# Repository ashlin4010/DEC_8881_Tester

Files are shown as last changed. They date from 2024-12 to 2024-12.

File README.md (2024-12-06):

# DEC_8881_Tester
A simple tester for DEC 8881 chips.

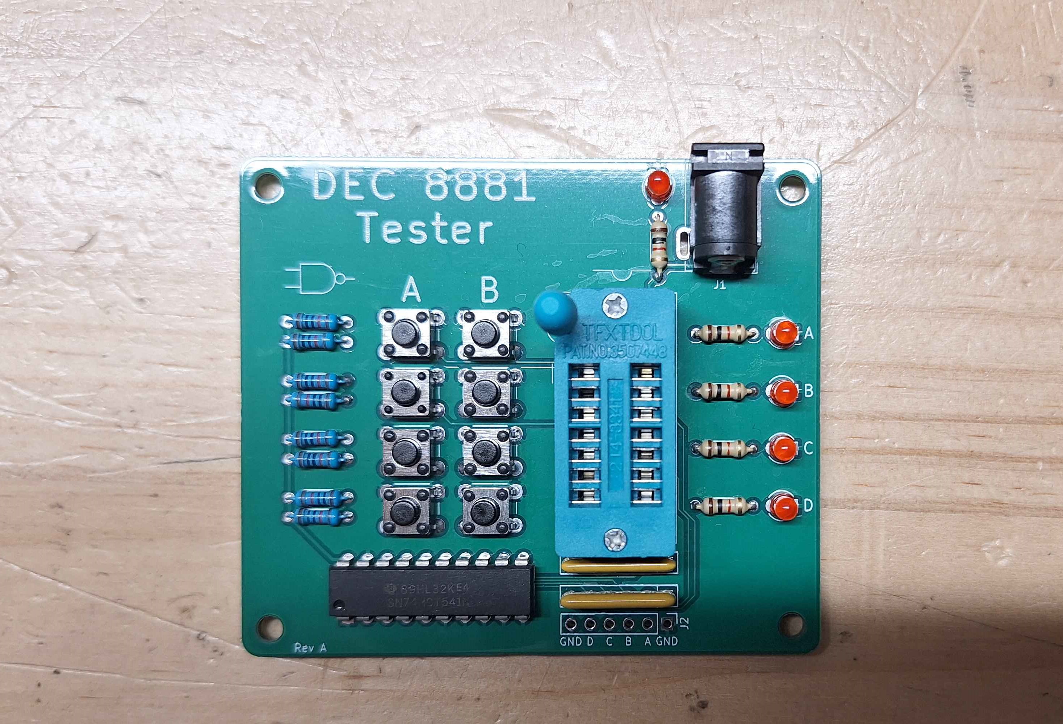
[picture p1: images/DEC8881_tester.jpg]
Chip Tester PCB


## Usage ##
 1. Plug it into 5 volt power centre positive power.
 2. Install chip
 3. Press Buttons

## Bill of materials ##

| Quantity | Part | Link |
|:---:|:---:|:---:|
| 5 | 1K Resistor |  |
| 8 | 10K Resistor |  |
| 8 | Push Button | https://www.digikey.co.nz/en/products/detail/same-sky-formerly-cui-devices/TS02-66-70-BK-160-LCR-D/15634243 |
| 1 | Barrel Jack | https://www.digikey.co.nz/en/products/detail/same-sky-formerly-cui-devices/PJ-037A/1644545 |
| 1 | DIP-14 ZIF Socket | https://www.aliexpress.com/item/1005007048855354.html |
| 1 | 74HCT541 | https://www.digikey.co.nz/en/products/detail/texas-instruments/SN74HCT541N/277265 |
| 1 | 390ohm Bussed | https://www.digikey.co.nz/en/products/detail/bourns-inc/4606X-101-391LF/1088986 |
| 1 | 180ohm Bussed | https://www.digikey.co.nz/en/products/detail/bourns-inc/4606X-101-181LF/1088969 |
| 5 | 3mm LED RED |  |

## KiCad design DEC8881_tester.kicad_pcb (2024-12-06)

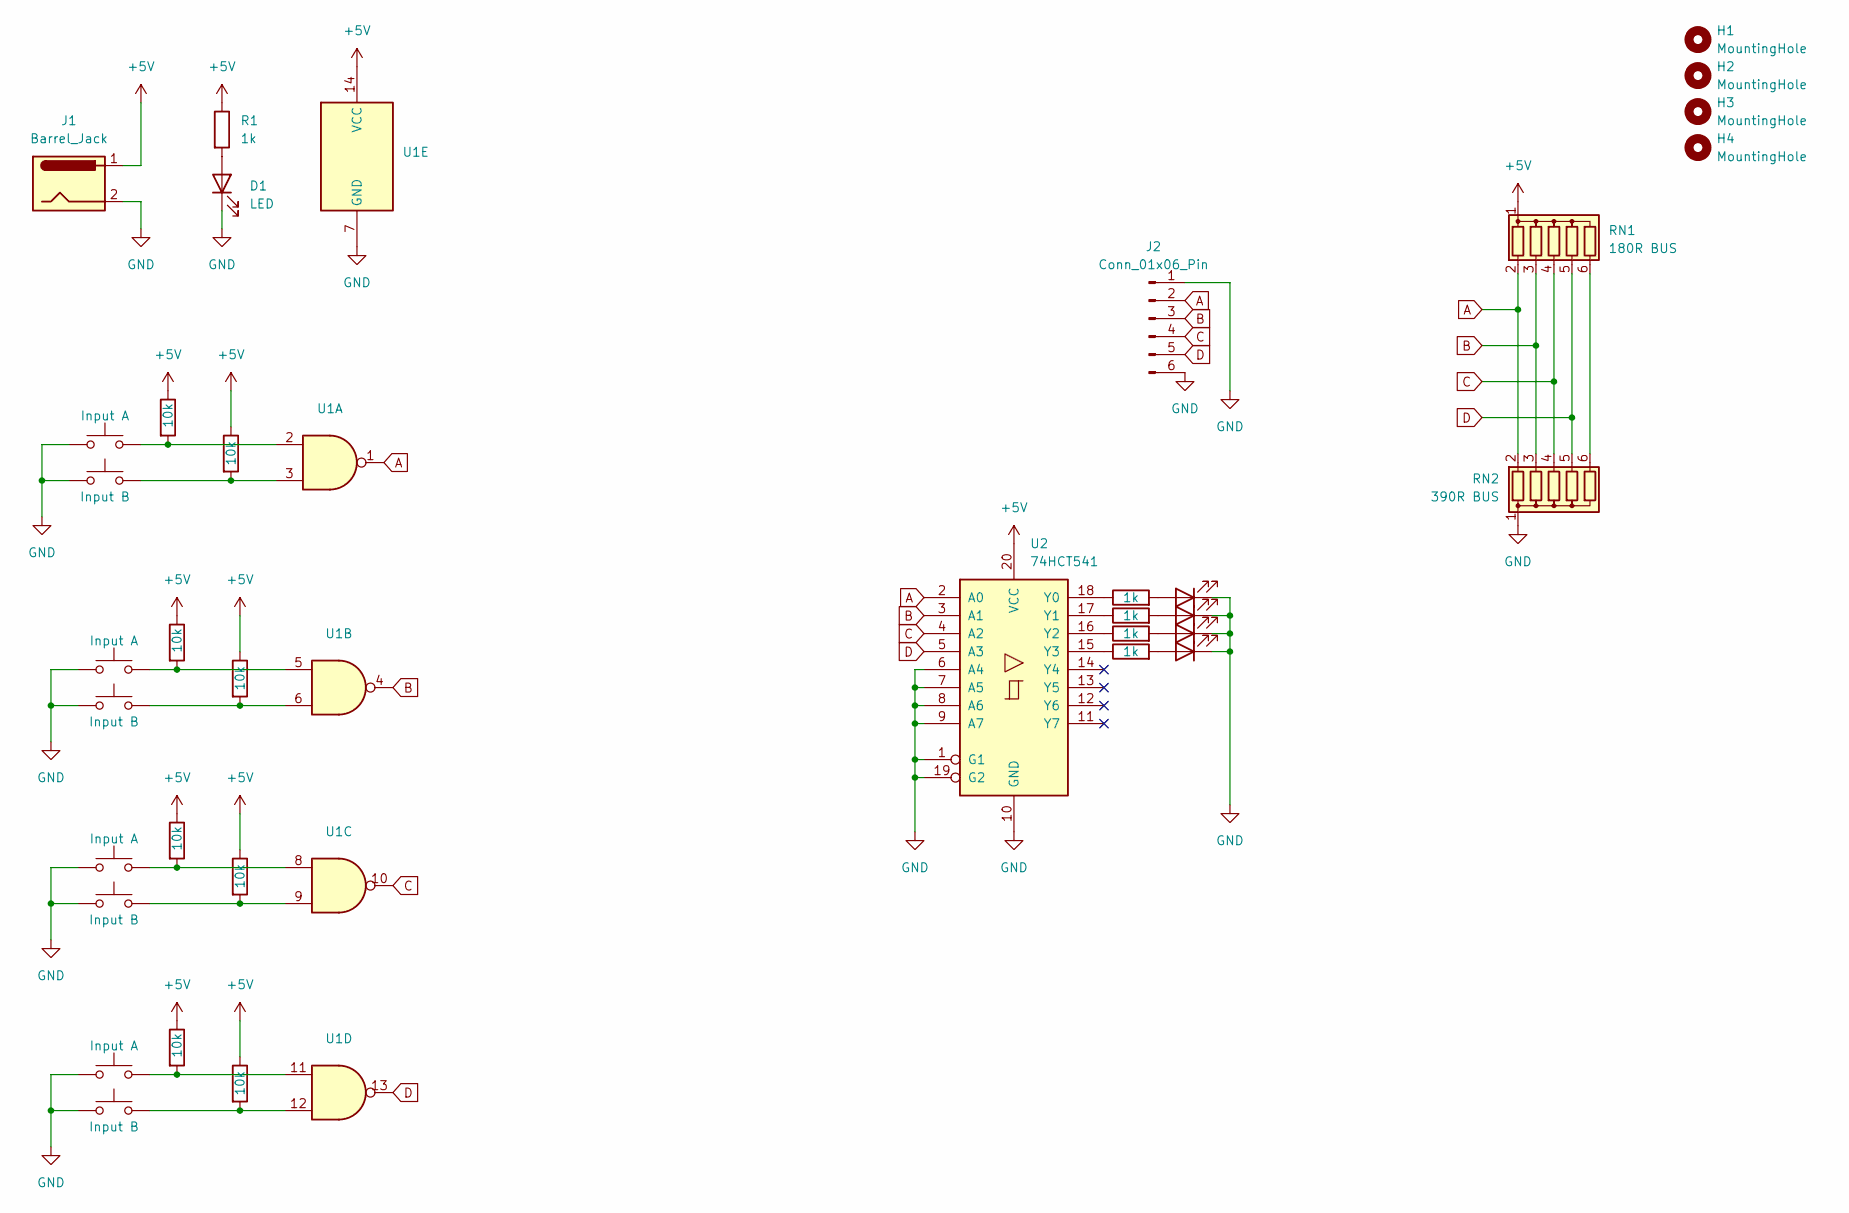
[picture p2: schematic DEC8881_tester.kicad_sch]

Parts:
D1, D2, D3, D4, D5: LED; LED_D3.0mm
H1, H2, H3, H4: MountingHole; MountingHole_3.2mm_M3
J1: Barrel_Jack; BarrelJack_GCT_DCJ200-10-A_Horizontal
J2: Conn_01x06_Pin; PinHeader_1x06_P2.54mm_Vertical
R1, R10, R11, R12, R13: 1k; R_Axial_DIN0204_L3.6mm_D1.6mm_P7.62mm_Horizontal
R2, R3, R4, R5, R6, R7, R8, R9: 10k; R_Axial_DIN0204_L3.6mm_D1.6mm_P7.62mm_Horizontal
RN1: 180R BUS; R_Array_SIP6
RN2: 390R BUS; R_Array_SIP6
SW1, SW3, SW5, SW7: Input A; SW_PUSH_6mm_H4.3mm
SW2, SW4, SW6, SW8: Input B; SW_PUSH_6mm_H4.3mm
U1: DIP_Socket-14_W4.3_W5.08_W7.62_W10.16_W10.9_3M_214-3339-00-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
U2: 74HCT541; DIP-20_W7.62mm

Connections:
+5V: J1.1, R1.1, R2.1, R3.1, R4.1, R5.1, R6.1, R7.1, R8.1, R9.1, RN1.1 (common), U1.14 (VCC), U2.20 (VCC)
A: J2.2, RN1.2 (R1), RN2.2 (R1), U1.1, U2.2 (A0)
B: J2.3, RN1.3 (R2), RN2.3 (R2), U1.4, U2.3 (A1)
C: J2.4, RN1.4 (R3), RN2.4 (R3), U1.10, U2.4 (A2)
D: J2.5, RN1.5 (R4), RN2.5 (R4), U1.13, U2.5 (A3)
GND: D1.1 (K), D2.1 (K), D3.1 (K), D4.1 (K), D5.1 (K), J1.2, J2.1, J2.6, RN2.1 (common), SW1.1, SW2.1, SW3.1, SW4.1, SW5.1, SW6.1, SW7.1, SW8.1, U1.7 (GND), U2.1 (G1), U2.6 (A4), U2.7 (A5), U2.8 (A6), U2.9 (A7), U2.10 (GND), U2.19 (G2)
unnamed: D1.2 (A), R1.2
unnamed: D2.2 (A), R10.2
unnamed: D3.2 (A), R11.2
unnamed: D4.2 (A), R12.2
unnamed: D5.2 (A), R13.2
unnamed: R2.2, SW1.2, U1.2
unnamed: R3.2, SW2.2, U1.3
unnamed: R4.2, SW3.2, U1.5
unnamed: R5.2, SW4.2, U1.6
unnamed: R6.2, SW5.2, U1.8
unnamed: R7.2, SW6.2, U1.9
unnamed: R8.2, SW7.2, U1.11
unnamed: R9.2, SW8.2, U1.12
unnamed: RN1.6 (R5), RN2.6 (R5)
unnamed: R10.1, U2.18 (Y0)
unnamed: R11.1, U2.17 (Y1)
unnamed: R12.1, U2.16 (Y2)
unnamed: R13.1, U2.15 (Y3)

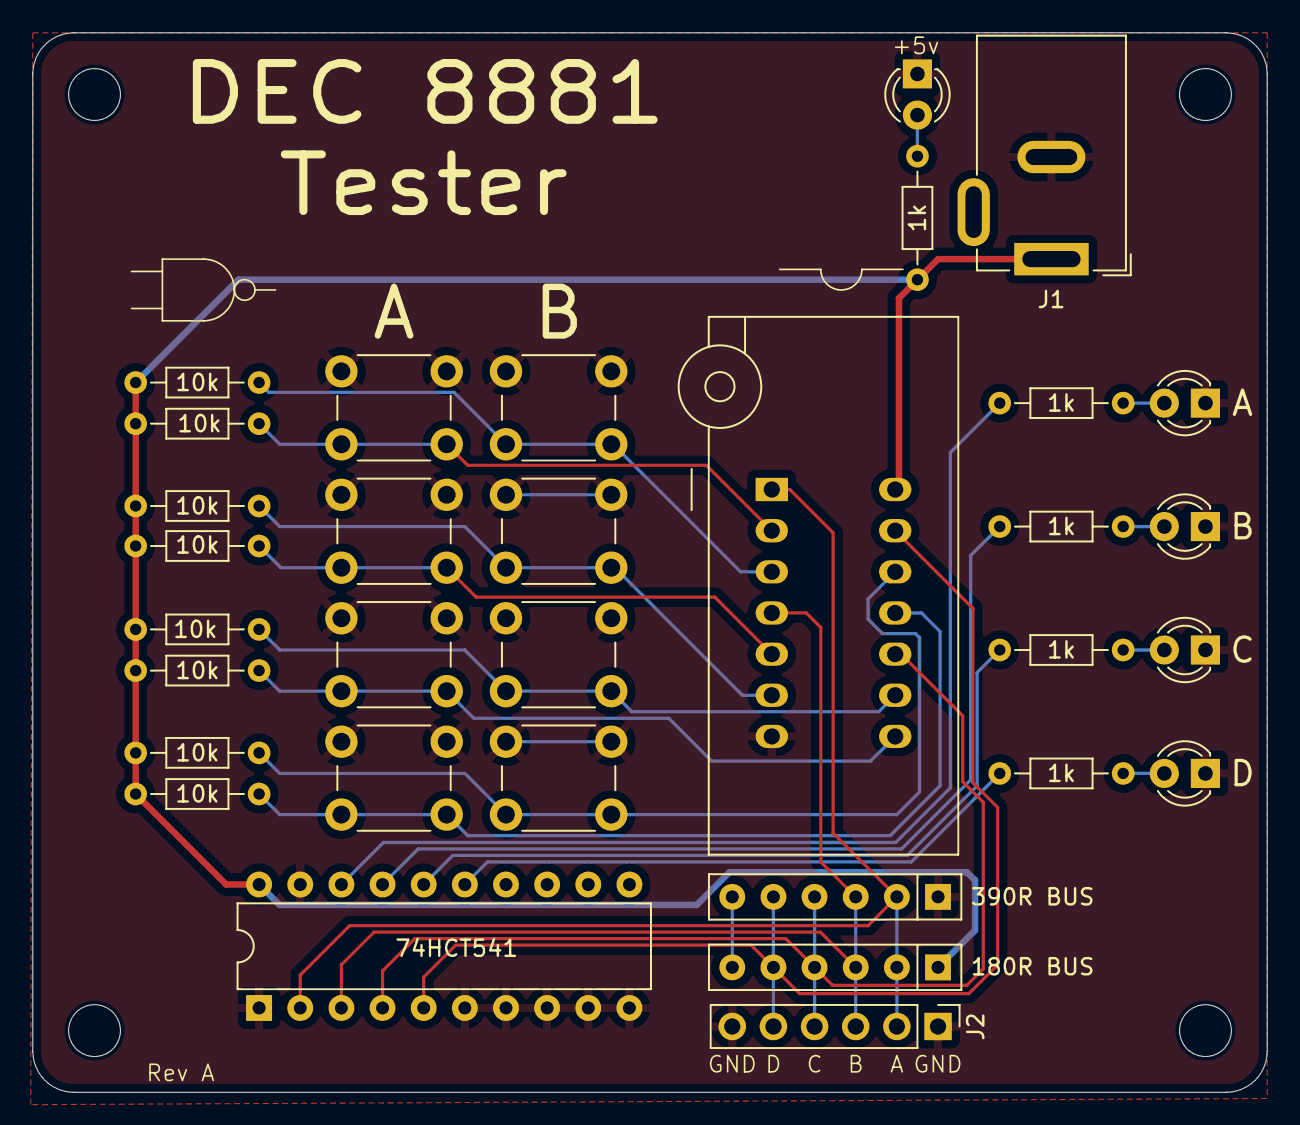
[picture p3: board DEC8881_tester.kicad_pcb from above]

Board: 2 copper layers, 76.2 x 65.4 mm, 36 parts (0 on the bottom side), 24 nets.

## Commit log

2024-11-19 Added PCB files
    [DEC8881_tester-B_Cu.gbl, DEC8881_tester-B_Mask.gbs, DEC8881_tester-B_Silkscreen.gbo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]
2024-12-06 Added image and new manufacturer files
    [DEC8881_tester-B_Cu.gbl, DEC8881_tester-B_Mask.gbs, DEC8881_tester-B_Silkscreen.gbo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]
2024-12-06 Fix BOM
